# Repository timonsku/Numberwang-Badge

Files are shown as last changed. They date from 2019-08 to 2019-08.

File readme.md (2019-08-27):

Numberwang Badge
========

This is a stupid last minute project that came into existence for CCCamp19. If you are reading this you probably got an unpopulated PCB from me.

I did not expect that so many people got interested in it, so the documentation might be a little lacking. If you actually solder the badge and have any issue just create a Github issue here so others can profit from the discussion too.

THERE IS ONE BUG IN THE CIRCUIT. Please see the audio bodge fix png, in the hurry I misnamed a signal and it was NC when it was supposed to connect to the I2S amp. You need to solder one bodge wire, other than that all works fine.

The MCU on the board is the ATSAMD21G18, the pinout used is the same from the Adafruit Itsy Bitsy. I tried to stay as close to the Itsy Bitsy as possible so you can just refer to their documentation if you got any questions regarding pinout: https://learn.adafruit.com/introducing-itsy-bitsy-m0

Circuit wise its also really close (thanks to Adafruit for being open source), only difference is the added lipo charger which you usually find on Adafruit Feathers. It uses the same JST-PH 2.0 SMT right angle connector but the polarity is reversed to what the Adafruit batteries use! Why? Because I can't buy them in Germany and all other batteries with this connector use the opposite polarity so I went with what the batteries on Amazon offer.

Quick note on the BOM, the design isn't all that smart, there are some components that appear in both 0603 and 0805, you can get away with using just 0603 or just 0805, no need to get both sizes.

I think you can get all components from Mouser if you want, they will just be more expensive than getting them from LCSC. Especially the JST-PH, if you need that from 'not LCSC' go with Digikey or buy the over priced reselled one that is available from Mouser as an Adafruit product.

If anything is unclear in the BOM, please create an issue, I respond fairly quickly usually.

There is an SWD testpad pinout in 2.54mm raster, I used pogo pins for programming but you can also just use a right angle pin header that you press against the pad. Might be a bit flaky but works for flashing the bootloader. Here a tutorial from Adafruit that explains flashing with different programmers (can also use a Pi or other ARM MCU to flash if you dont got an SWD capable flasher)
https://learn.adafruit.com/how-to-program-samd-bootloaders

UF2 bootloader binary is provided in the repo as well as a slightly customized CircuitPython firmware (same as Itsy Bitsy M0 just different flash IC set). When using online docs you can always refer to Itsy Bitsy M0.
Same for Arduino, just get the Adafruit SAMD board package and choose Itsy Bitsy M0 as target.

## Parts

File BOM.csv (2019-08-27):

Qty | Value | Device | Package | Parts | Description | Order Link | DESCRIPTION | MANUFACTURER_NAME | MANUFACTURER_PART_NUMBER | MF | MOUSER_PART_NUMBER | MOUSER_PRICE-STOCK | MP | PACKAGE | PRICE | PROD_ID | RS_PART_NUMBER | RS_PRICE-STOCK
1 |  | USB_MICRO-B_FEMALE-SMT | USB-B-MICRO-SMD | J1 | USB Type Micro-B Connector | https://lcsc.com/product-detail/Micro-USB-Connectors_Korean-Hroparts-Elec-U-F-M5SW-Y-3_C106820.html | This part on mouser should work just as fine https://www.mouser.de/ProductDetail/Hirose-Connector/ZX62-B-5PA33 |  |  |  |  |  |  |  |  | CONN-11752
1 | 0.1uF | CAP_CERAMIC_0805MP | _0805MP | C8 | Ceramic Capacitors | Generic |  | Generic
2 | 100k | RESISTOR_0603MP | _0603MP | R5, R7 | Resistors | Generic |  | Generic
1 | 10K | RESISTOR_0805MP | _0805MP | R1 | Resistors | Generic |  | Generic
1 | 10K | RESISTOR_0603MP | _0603MP | R6 | Resistors | Generic |  | Generic
2 | 10uF | CAP_CERAMIC_0805MP | _0805MP | C12, C13 | Ceramic Capacitors | Generic |  | Generic
3 | 10µF | CAP_CERAMIC_0805MP | _0805MP | C1, C4, C11 | Ceramic Capacitors | Generic |  | Generic
1 | 1K | RESISTOR_0603MP | _0603MP | R4 | Resistors | Generic |  | Generic
1 | 1M | RESISTOR_0805MP | _0805MP | R2 | Resistors | Generic |  | Generic
3 | 1uF | CAP_CERAMIC_0603MP | _0603MP | C2, C9, C10 | Ceramic Capacitors | Generic |  | Generic
1 | 2.2K | RESISTOR_0603MP | _0603MP | R3 | Resistors | Generic |  | Generic
2 | 220pF | CAP_CERAMIC_0805MP | _0805MP | C14, C15 | Ceramic Capacitors | Generic |  | Generic
1 | AP2112-3.3 | VREG_SOT23-5 | SOT23-5 | U1 | SOT23-5 Fixed Voltage Regulators | https://lcsc.com/product-detail/Low-Dropout-Regulators-LDO_DIODES_AP2112K-3-3TRG1_AP2112K-3-3TRG1_C51118.html |  |  | AP2112K-3-3
1 | ATSAMD21G18 | ATSAMD21G_QFN | TQFN48_7MM | U$13 |  | https://www.mouser.de/ProductDetail/Microchip-Technology-Atmel/ATSAMD21G18A-MUT |  | Microchip | ATSAMD21G18A-MUT
1 | CMS-151135-078SP | CMS-151135-078SP | CMS151135078SP | LS1 | Speakers & Transducers 0.7W 8ohm 550Hz 15x11mm Solder Pads | https://www.mouser.com/Search/Refine.aspx?Keyword=490-CMS-151135-078SP | Speakers & Transducers 0.7W 8ohm 550Hz 15x11mm Solder Pads | CUI | CMS-151135-078L100 |  | 490-CMS-151135-078L100 | https://www.mouser.com/Search/Refine.aspx?Keyword=490-CMS-151135-078SP
2 | Ferrite | FERRITE | 603 | FB3, FB4 | Ferrite Bead | https://www.mouser.de/ProductDetail/CUI/CMS-151135-078L100 |  |  | MAF1608GAD471CT000
2 | JSTPH | CON_JST_PH_2PIN | JSTPH2 | X1, X2 | JST 2-Pin Right-Angle Connector | https://lcsc.com/product-detail/Wire-To-Board-Wire-To-Wire-Connector_Shenzhen-Cankemeng-2001series-socket-1-2P-2mm_C132500.html
1 | MAX98357A | AUDIOAMP_MAX98357 | QFN16_3MM | U5 | MAX98357 - 3.2W I2S Mono Audio Amp | https://www.mouser.de/ProductDetail/Maxim-Integrated/MAX98357AETE%2bT
1 | MBR120 | DIODE-SCHOTTKYSOD-123 | SOD-123 | D2 | 2A rating or better, SOD-214 package also works (I used that because I still had it) f.e. B230A | https://lcsc.com/product-detail/Schottky-Barrier-Diodes-SBD_Shandong-Jingdao-Microelectronics-DS24W_C108810.html
1 | MCP73831T | MCP73831/2 | SOT23-5@1 | U4 | MCP73831/2 LIPO Charger SOT23-5 | https://www.mouser.de/ProductDetail/Microchip-Technology/MCP73831T-2ACI-OT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
1 | ORANGE | LED0805_NOOUTLINE | CHIPLED_0805_NOOUTLINE | CHG1 | LED | Generic
1 | RED | LED0805_NOOUTLINE | CHIPLED_0805_NOOUTLINE | L1 | LED | Generic
1 | SI2308CDS-T1-GE3 | MOSFET-NWIDE | SOT23-WIDE | Q1 | N-Channel Mosfet | https://www.mouser.de/ProductDetail/78-SI2308CDS-T1-GE3 |  |  | SI2308CDS-T1-GE3
1 | SPST_TACT-KMR2 | SPST_TACT-KMR2 | KMR2 | SW2 | SMT 6mm switch, EVQQ2 series | https://lcsc.com/product-detail/Tactile-Switches_C-K_KMR221GLFS_C-K-KMR221GLFS_C72443.html
1 | SSSS811101 | SSSS811101 | SSSS811101 | S1 | Slide Switches SPDT HORZ GRND 1.5mm | https://lcsc.com/product-detail/Toggle-Switches_ALPS_SSSS811101_SSSS811101_C109335.html | Slide Switches SPDT HORZ GRND 1.5mm | ALPS | SSSS811101 |  | 688-SSSS811101 | https://www.mouser.com/Search/Refine.aspx?Keyword=688-SSSS811101 |  |  |  |  | 1238939 | http://uk.rs-online.com/web/p/products/1238939
1 | W25Q16JVSSIQ | W25Q16JVSSIQ | SOIC127P790X216-8N | U2 | 3v 16m-Bit Serial Flash Memory With Dual | https://lcsc.com/product-detail/FLASH_Winbond-Elec-W25Q16JVSSIQTR_C131025.html | 3v 16m-Bit Serial Flash Memory With Dual |  |  | Winbond Electronics |  |  | W25Q16JVSSIQ | SOIC-8 Winbond | None

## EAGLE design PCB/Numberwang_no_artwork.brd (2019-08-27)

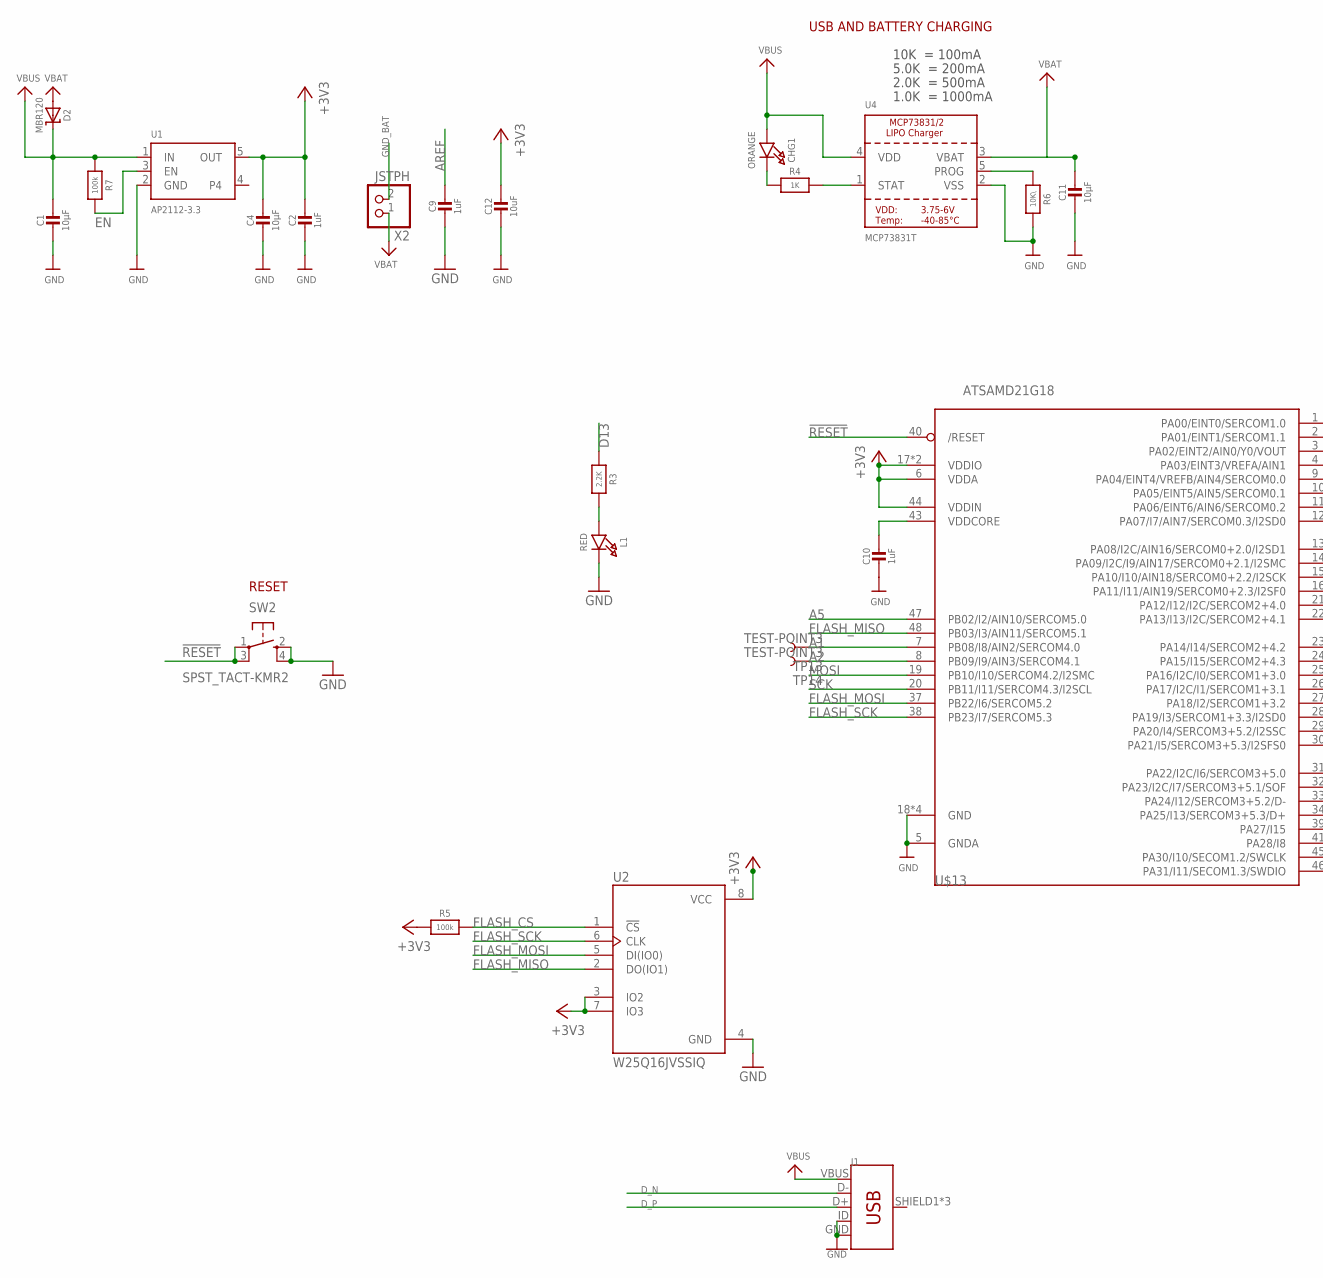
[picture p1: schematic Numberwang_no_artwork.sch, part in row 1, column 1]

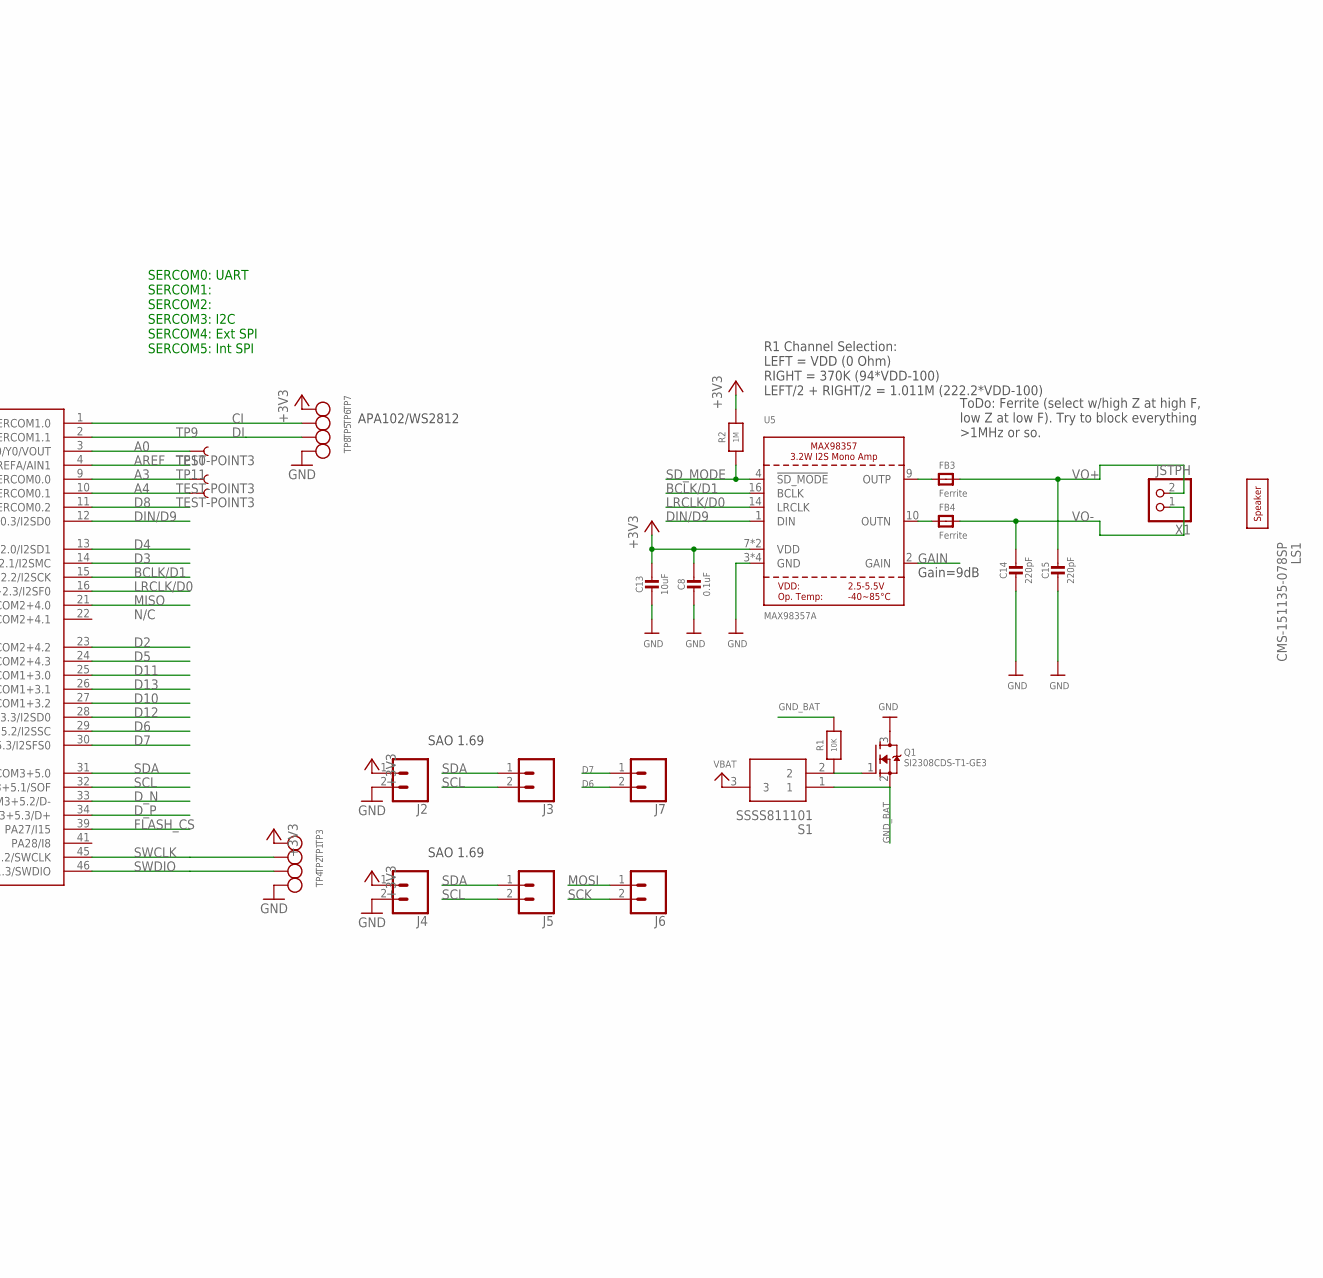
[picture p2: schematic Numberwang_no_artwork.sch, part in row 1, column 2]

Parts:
C1, C4, C11: 10µF; _0805MP
C2, C9, C10: 1uF; _0603MP
C8: 0.1uF; _0805MP
C12, C13: 10uF; _0805MP
C14, C15: 220pF; _0805MP
CHG1: ORANGE; CHIPLED_0805_NOOUTLINE
D2: MBR120; SOD-123
FB3, FB4: Ferrite; 0603
J1: USB_MICRO-B_FEMALE-SMT; USB-B-MICRO-SMD
J2, J3, J4, J5, J6, J7: CONN_02; 1X02
L1: RED; CHIPLED_0805_NOOUTLINE
LS1: CMS-151135-078SP; CMS151135078SP
Q1: SI2308CDS-T1-GE3; SOT23-WIDE
R1: 10K; _0805MP
R2: 1M; _0805MP
R3: 2.2K; _0603MP
R4: 1K; _0603MP
R5, R7: 100k; _0603MP
R6: 10K\; _0603MP
S1: SSSS811101
SW2: SPST_TACT-KMR2; KMR2
TP1, TP2, TP3, TP4, TP5, TP6, TP7, TP8: TESTPOINTROUND2MM; TESTPOINT_ROUND_2MM
TP9, TP10, TP11, TP13, TP14: TEST-POINT3; PAD.03X.03
U1: AP2112-3.3; SOT23-5
U2: W25Q16JVSSIQ; SOIC127P790X216-8N
U4: MCP73831T; SOT23-5@1
U5: MAX98357A; QFN16_3MM
U$13: ATSAMD21G18; TQFN48_7MM
X1, X2: JSTPH; JSTPH2

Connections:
!RESET: SW2.1, SW2.3 (P1), U$13.40 (/RESET)
+3V3: C2.1, C4.1, C8.1, C12.1, C13.1, J2.1, J4.1, R2.2, R5.1, TP3.P$1, TP7.P$1, U1.5 (OUT), U2.3 (IO2), U2.7 (IO3), U2.8 (VCC), U5.7 (VDD), U5.8 (VDD), U$13.6 (VDDA), U$13.17 (VDDIO), U$13.36 (VDDIO), U$13.44 (VDDIN)
A0: TP9.P$1, U$13.3 (PA02/EINT2/AIN0/Y0/VOUT)
A1: TP13.P$1, U$13.7 (PB08/I8/AIN2/SERCOM4.0)
A2: TP14.P$1, U$13.8 (PB09/I9/AIN3/SERCOM4.1)
A3: TP10.P$1, U$13.9 (PA04/EINT4/VREFB/AIN4/SERCOM0.0)
A4: TP11.P$1, U$13.10 (PA05/EINT5/AIN5/SERCOM0.1)
A5: U$13.47 (PB02/I2/AIN10/SERCOM5.0)
AREF: C9.1, U$13.4 (PA03/EINT3/VREFA/AIN1)
BCLK/D1: U5.16 (BCLK), U$13.15 (PA10/I10/AIN18/SERCOM0+2.2/I2SCK)
CI: TP6.P$1, U$13.1 (PA00/EINT0/SERCOM1.0)
D2: U$13.23 (PA14/I14/SERCOM2+4.2)
D3: U$13.14 (PA09/I2C/I9/AIN17/SERCOM0+2.1/I2SMC)
D4: U$13.13 (PA08/I2C/AIN16/SERCOM0+2.0/I2SD1)
D5: U$13.24 (PA15/I15/SERCOM2+4.3)
D6: J7.2, U$13.29 (PA20/I4/SERCOM3+5.2/I2SSC)
D7: J7.1, U$13.30 (PA21/I5/SERCOM3+5.3/I2SFS0)
D8: U$13.11 (PA06/EINT6/AIN6/SERCOM0.2)
D10: U$13.27 (PA18/I2/SERCOM1+3.2)
D11: U$13.25 (PA16/I2C/I0/SERCOM1+3.0)
D12: U$13.28 (PA19/I3/SERCOM1+3.3/I2SD0)
D13: R3.1, U$13.26 (PA17/I2C/I1/SERCOM1+3.1)
DI: TP5.P$1, U$13.2 (PA01/EINT1/SERCOM1.1)
DIN/D9: U5.1 (DIN), U$13.12 (PA07/I7/AIN7/SERCOM0.3/I2SD0)
D_N: J1.D-, U$13.33 (PA24/I12/SERCOM3+5.2/D-)
D_P: J1.D+, U$13.34 (PA25/I13/SERCOM3+5.3/D+)
EN: R7.2, U1.3 (EN)
FLASH_CS: R5.2, U2.1 (!CS), U$13.39 (PA27/I15)
FLASH_MISO: U2.2 (DO(IO1)), U$13.48 (PB03/I3/AIN11/SERCOM5.1)
FLASH_MOSI: U2.5 (DI(IO0)), U$13.37 (PB22/I6/SERCOM5.2)
FLASH_SCK: U2.6 (CLK), U$13.38 (PB23/I7/SERCOM5.3)
GAIN: U5.2 (GAIN)
GND: C1.2, C2.2, C4.2, C8.2, C9.2, C10.2, C11.2, C12.2, C13.2, C14.2, C15.2, J1.GND, J1.ID, J2.2, J4.2, L1.C, Q1.3 (D), R6.2, SW2.2 (S), SW2.4 (S1), TP4.P$1, TP8.P$1, U1.2 (GND), U2.4 (GND), U4.2 (VSS), U5.3 (GND), U5.11 (GND), U5.15 (GND), U5.THERMAL (GND), U$13.5 (GNDA), U$13.18 (GND), U$13.35 (GND), U$13.42 (GND), U$13.THERMAL (GND)
GND_BAT: Q1.2 (S), R1.2, S1.1, X2.2
LRCLK/D0: U5.14 (LRCLK), U$13.16 (PA11/I11/AIN19/SERCOM0+2.3/I2SF0)
MISO: U$13.21 (PA12/I12/I2C/SERCOM2+4.0)
MOSI: J6.1, U$13.19 (PB10/I10/SERCOM4.2/I2SMC)
unnamed: FB4.1, U5.10 (OUTN)
unnamed: L1.A, R3.2
unnamed: FB3.1, U5.9 (OUTP)
unnamed: Q1.1 (G), R1.1, S1.2
unnamed: CHG1.C, R4.1
unnamed: R4.2, U4.1 (STAT)
unnamed: R6.1, U4.5 (PROG)
SCK: J6.2, U$13.20 (PB11/I11/SERCOM4.3/I2SCL)
SCL: J3.2, J5.2, U$13.32 (PA23/I2C/I7/SERCOM3+5.1/SOF)
SDA: J3.1, J5.1, U$13.31 (PA22/I2C/I6/SERCOM3+5.0)
SD_MODE: R2.1, U5.4 (!SD_MODE)
SWCLK: TP1.P$1, U$13.45 (PA30/I10/SECOM1.2/SWCLK)
SWDIO: TP2.P$1, U$13.46 (PA31/I11/SECOM1.3/SWDIO)
VBAT: C11.1, D2.A, S1.3, U4.3 (VBAT), X2.1
VBUS: C1.1, CHG1.A, D2.C, J1.VBUS, R7.1, U1.1 (IN), U4.4 (VDD)
VDDCORE1: C10.1, U$13.43 (VDDCORE)
VO+: C15.1, FB3.2, X1.2
VO-: C14.1, FB4.2, X1.1

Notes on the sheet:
RESET
N/C
SERCOM0: UART SERCOM1: SERCOM2: SERCOM3: I2C SERCOM4: Ext SPI SERCOM5: Int SPI
10K = 100mA
5.0K = 200mA
2.0K = 500mA
1.0K = 1000mA
USB AND BATTERY CHARGING
APA102/WS2812
SAO 1.69
R1 Channel Selection: LEFT = VDD (0 Ohm) RIGHT = 370K (94*VDD-100) LEFT/2 + RIGHT/2 = 1.011M (222.2*VDD-100)
ToDo: Ferrite (select w/high Z at high F, low Z at low F). Try to block everything >1MHz or so.
Gain=9dB

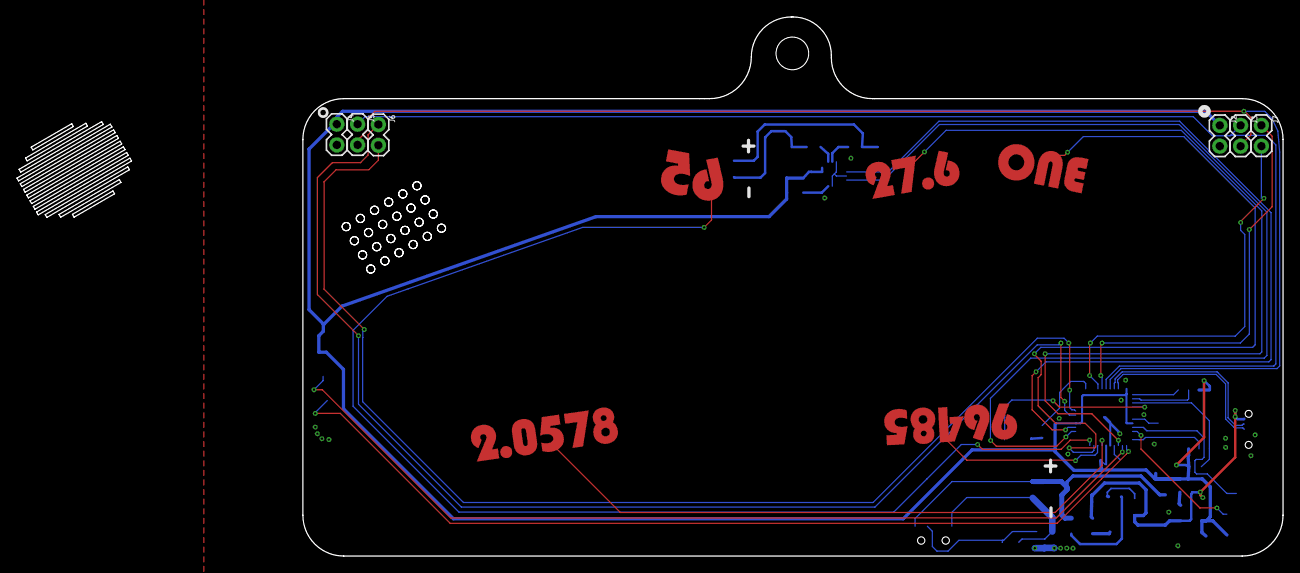
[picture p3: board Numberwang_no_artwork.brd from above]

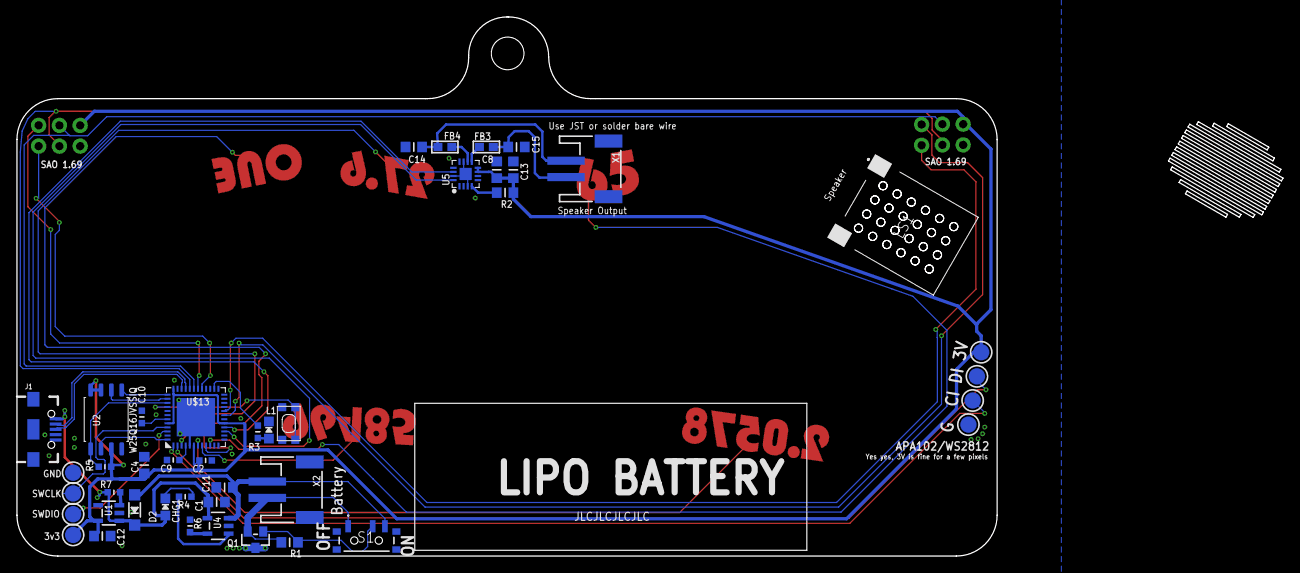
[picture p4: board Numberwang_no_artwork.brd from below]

Board: 2 copper layers, 120.0 x 66.0 mm, 54 parts (43 on the bottom side), 44 nets.

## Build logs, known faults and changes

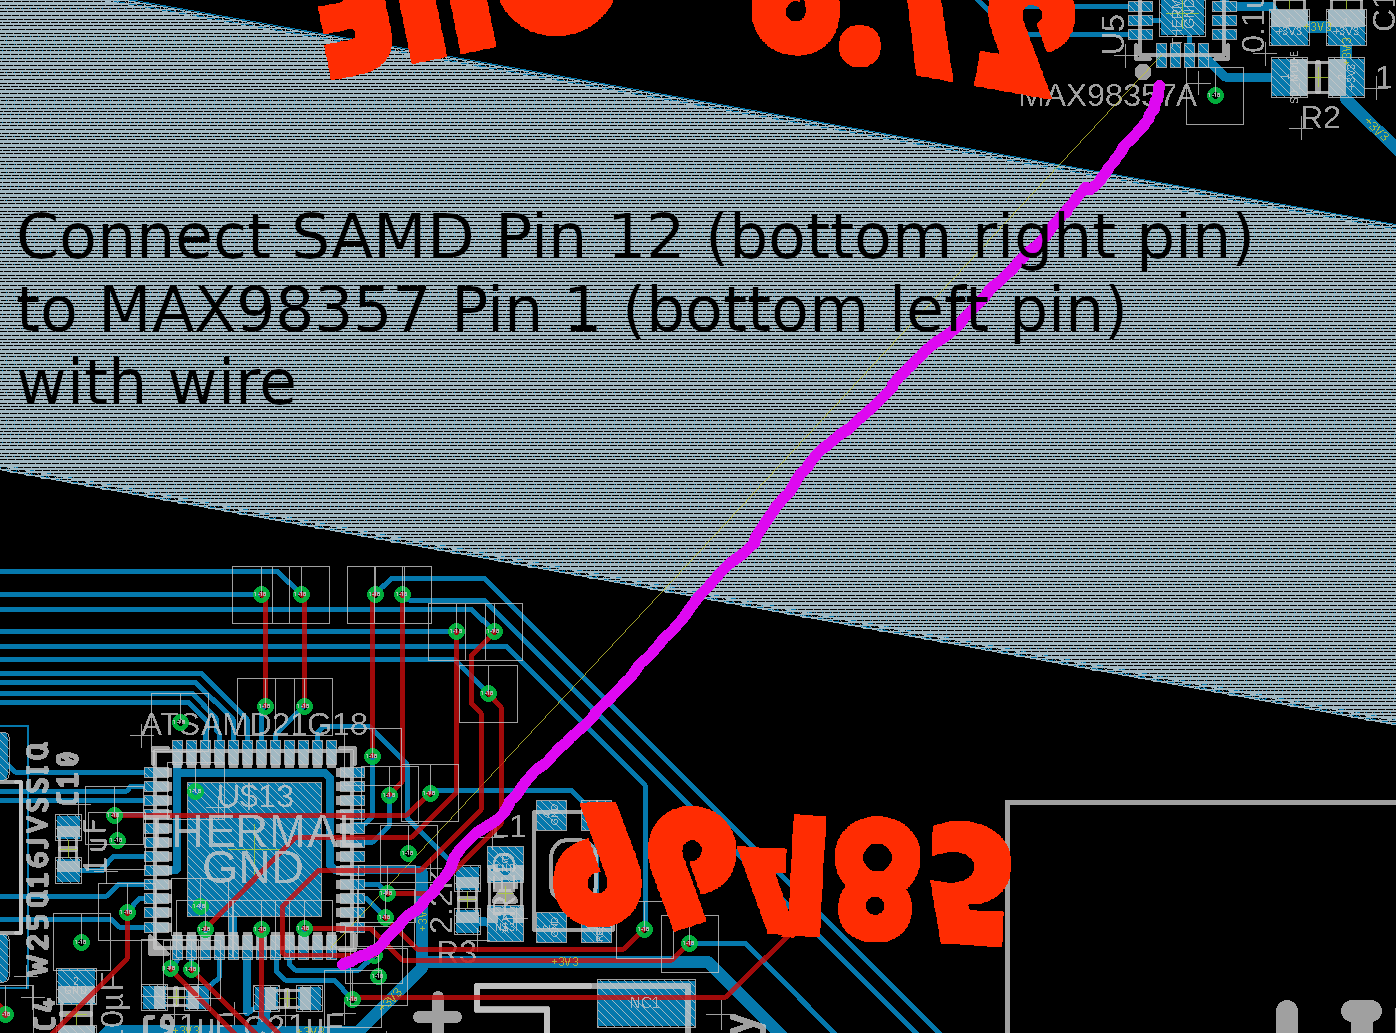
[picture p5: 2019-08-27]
Bodge-Fix-Audio.png

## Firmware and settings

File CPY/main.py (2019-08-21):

import audioio
import board
import audiobusio
import time
import random
import adafruit_dotstar as dotstar
import adafruit_fancyled.adafruit_fancyled as fancy
import touchio




 
# # For Feather M0 Express, ItsyBitsy M0 Express, Metro M0 Express
audio = audiobusio.I2SOut(board.D1, board.D0, board.D9)
# # For Feather M4 Express
# # audio = audiobusio.I2SOut(board.D1, board.D10, board.D11)
# # For Metro M4 Express
# # audio = audiobusio.I2SOut(board.D3, board.D9, board.D8)
 
# while True:
#     audio.play(wave)
#     while audio.playing:
#         pass

touch1 = touchio.TouchIn(board.A0)
touch2 = touchio.TouchIn(board.A1)
touch3 = touchio.TouchIn(board.A2)
touch4 = touchio.TouchIn(board.A3)
touch5 = touchio.TouchIn(board.A4)

num_leds = 15

# On-board DotStar for boards including Gemma, Trinket, and ItsyBitsy
pixels = dotstar.DotStar(board.APA102_MOSI, board.APA102_SCK, num_leds, brightness=1.0,
                           auto_write=False)

# Using a DotStar Digital LED Strip with 30 LEDs connected to hardware SPI
# dots = dotstar.DotStar(board.SCK, board.MOSI, 30, brightness=0.2)

# Using a DotStar Digital LED Strip with 30 LEDs connected to digital pins
# dots = dotstar.DotStar(board.D6, board.D5, 30, brightness=0.2)
# Declare a 6-element RGB rainbow palette
palette = [fancy.CRGB(1.0, 0.0, 0.0), # Red
           fancy.CRGB(0.5, 0.5, 0.0), # Yellow
           fancy.CRGB(0.0, 1.0, 0.0), # Green
           # fancy.CRGB(0.0, 0.5, 0.5), # Cyan
           fancy.CRGB(0.0, 0.0, 1.0), # Blue
           fancy.CRGB(0.5, 0.0, 0.5)] # Magenta




def numberwang():
	thats_numberwang_file = open("thats_numberwang.wav", "rb")
	thats_numberwang = audioio.WaveFile(thats_numberwang_file)
	offset = 0  # Positional offset into color palette to get it to 'spin'
	audio.play(thats_numberwang)
	while audio.playing:
	    for i in range(num_leds):
	        # Load each pixel's color from the palette using an offset, run it
	        # through the gamma function, pack RGB value and assign to pixel.
	        color = fancy.palette_lookup(palette, offset + i / num_leds)
	        color = fancy.gamma_adjust(color, brightness=0.25)
	        pixels[i] = color.pack()
	    pixels.show()

	    offset += 0.2  # Bigger number = faster spin
	thats_numberwang_file.close()
	return

def numberwang_intro():
	numberwang_intro_file = open("numberwang_intro_w_welcome.wav", "rb")
	numberwang_intro = audioio.WaveFile(numberwang_intro_file)
	offset = 0  # Positional offset into color palette to get it to 'spin'
	audio.play(numberwang_intro)
	while audio.playing:
	    for i in range(num_leds):
	        # Load each pixel's color from the palette using an offset, run it
	        # through the gamma function, pack RGB value and assign to pixel.
	        color = fancy.palette_lookup(palette, offset + i / num_leds)
	        color = fancy.gamma_adjust(color, brightness=0.25)
	        pixels[i] = color.pack()
	    pixels.show()

	    offset += 0.2  # Bigger number = faster spin
	numberwang_intro_file.close()
	return

def nine():
	audio_file = open("9.wav", "rb")
	wave = audioio.WaveFile(audio_file)
	offset = 0  # Positional offset into color palette to get it to 'spin'
	audio.play(wave)
	while audio.playing:
	    for i in range(num_leds):
	        # Load each pixel's color from the palette using an offset, run it
	        # through the gamma function, pack RGB value and assign to pixel.
	        color = fancy.palette_lookup(palette, offset + i / num_leds)
	        color = fancy.gamma_adjust(color, brightness=0.25)
	        pixels[i] = color.pack()
	    pixels.show()

	    offset += 0.2  # Bigger number = faster spin
	audio_file.close()
	return

def eight():
	audio_file = open("8_2.wav", "rb")
	wave = audioio.WaveFile(audio_file)
	offset = 0  # Positional offset into color palette to get it to 'spin'
	audio.play(wave)
	while audio.playing:
	    for i in range(num_leds):
	        # Load each pixel's color from the palette using an offset, run it
	        # through the gamma function, pack RGB value and assign to pixel.
	        color = fancy.palette_lookup(palette, offset + i / num_leds)
	        color = fancy.gamma_adjust(color, brightness=0.25)
	        pixels[i] = color.pack()
	    pixels.show()

	    offset += 0.2  # Bigger number = faster spin
	audio_file.close()
	return

def rotate():
	audio_file = open("lets_rotate_the_board.wav", "rb")
	wave = audioio.WaveFile(audio_file)
	offset = 0  # Positional offset into color palette to get it to 'spin'
	audio.play(wave)
	while audio.playing:
	    for i in range(num_leds):
	        # Load each pixel's color from the palette using an offset, run it
	        # through the gamma function, pack RGB value and assign to pixel.
	        color = fancy.palette_lookup(palette, offset + i / num_leds)
	        color = fancy.gamma_adjust(color, brightness=0.25)
	        pixels[i] = color.pack()
	    pixels.show()

	    offset += 0.2  # Bigger number = faster spin
	audio_file.close()
	return

while True:
    if touch1.value:
        print("Touched!")
        numberwang()
    if touch2.value:
        print("Touched!")
        numberwang_intro()
    if touch3.value:
        print("Touched!")
        nine()
    if touch4.value:
        print("Touched!")
        eight()
    if touch5.value:
        print("Touched!")
        rotate()
    time.sleep(0.15)



# 	    offset += 0.08  # Bigger number = faster spin
    
    # while audio.playing:
    #     pass
# # HELPERS
# # a random color 0 -> 224
# def random_color():
#     return random.randrange(0, 7) * 32


# # MAIN LOOP
# n_dots = len(dots)
# while True:
#     # Fill each dot with a random color
#     for dot in range(n_dots):
#         dots[dot] = (20, 150, 200)

#     time.sleep(.25)

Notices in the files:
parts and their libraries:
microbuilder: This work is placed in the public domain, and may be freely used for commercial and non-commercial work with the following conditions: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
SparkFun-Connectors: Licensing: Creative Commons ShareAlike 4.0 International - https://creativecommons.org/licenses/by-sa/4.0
